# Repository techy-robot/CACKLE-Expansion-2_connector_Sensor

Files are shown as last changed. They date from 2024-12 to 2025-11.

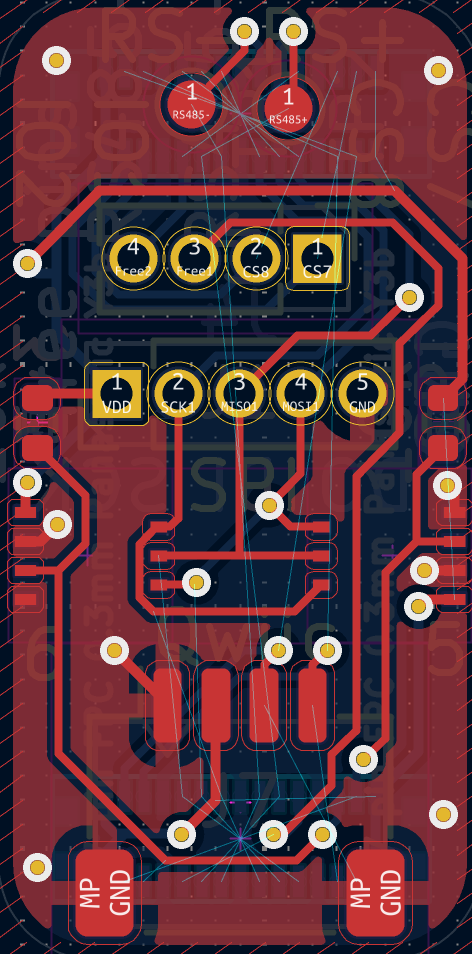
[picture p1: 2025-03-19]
media/2 conn Sensor Board Top.png

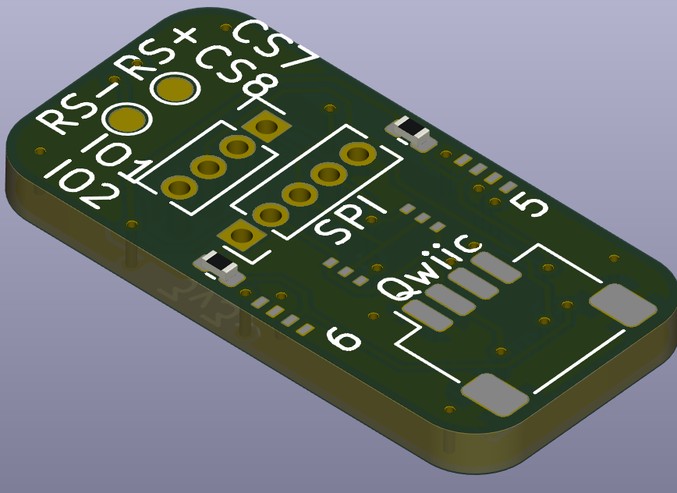
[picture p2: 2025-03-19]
media/2 conn Sensor Board 3D.png

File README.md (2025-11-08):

---
modified: 2025-11-07T22:07:14-07:00
---
# 2 connector Sensor Board

> [!TIP]
> This board is part of a larger modular control board ecosystem, [CACKLE](https://github.com/techy-robot/CACKLE)

This is a connector breakout board that spans between 2 vertical mezzanine connectors on a hub. It has one Qwiic connector, two nanoSPI connectors, and header breakouts for the free pins, chip select pins, and the SPI pins. It also has test pads for the RS485 bus. Essentially it breaks out every pin accessible via the mezzanine connectors.

One advantage this has over the single connector breakout is that this fits on normal sized hubs without needing a vertical spacer

Schematic PDF

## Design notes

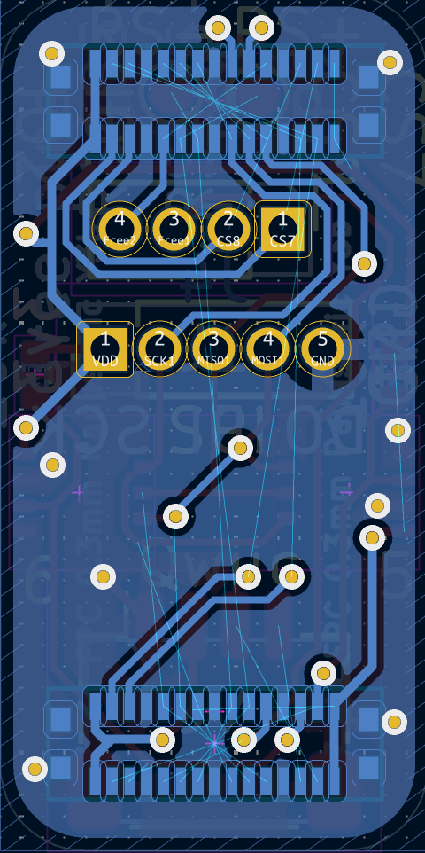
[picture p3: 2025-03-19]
media/2 conn Sensor Board Bottom.png

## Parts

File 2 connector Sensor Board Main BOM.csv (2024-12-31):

Id | Designator | Footprint | Quantity | Designation | Supplier and ref
1 | J1 | PinHeader_1x05_P1.27mm_Vertical | 1 | SPI
2 | J7 | JST_SH_SM04B-SRSS-TB_1x04-1MP_P1.00mm_Horizontal | 1 | JST SH
3 | R2,R4 | R_0402_1005Metric | 2 | 10k
4 | J3 | PinHeader_1x04_P1.27mm_Vertical | 1 | free pins
5 | J2,J5 | fpc_7pin_0.3mm_connector Panasonic | 2 | 7 pin FPC 0.3mm Panasonic Y3b
6 | J4,J15 | TE_mezzanine_conn_3-2363962-0 | 2 | TE 3-2363962-0 Connector

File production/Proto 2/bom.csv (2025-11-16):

Designator | Footprint | Quantity | Value | LCSC Part #
J1 | PinHeader_1x05_P1.27mm_Vertical | 1 | SPI
J15, J4 | TE_mezzanine_conn_3-2363962-0 | 2 | TE 3-2363962-0 Connector | C425104
J2, J5 | fpc_7pin_0.3mm_connector Panasonic | 2 | FPC 0.3mm Aces 51688-0070M
J3 | PinHeader_1x03_P1.27mm_Vertical | 1 | Prog Pins
J6 | PinHeader_1x02_P1.27mm_Vertical | 1 | Free Pins
J7 | JST_SH_SM04B-SRSS-TB_1x04-1MP_P1.00mm_Horizontal | 1 | JST SH | C160404
JP1, JP2 | SolderJumper-2_P1.3mm_Open_RoundedPad1.0x1.5mm | 2 | Jumper
R2, R4 | 0402 | 2 | 10k | C25744

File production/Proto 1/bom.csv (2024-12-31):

Designator | Footprint | Quantity | Value | LCSC Part #
J15, J4 | TE_mezzanine_conn_3-2363962-0 | 2 | TE 3-2363962-0 Connector | C425104
J7 | JST_SH_SM04B-SRSS-TB_1x04-1MP_P1.00mm_Horizontal | 1 | JST SH | C160404
R2, R4 | 0402 | 2 | 10k | C25744

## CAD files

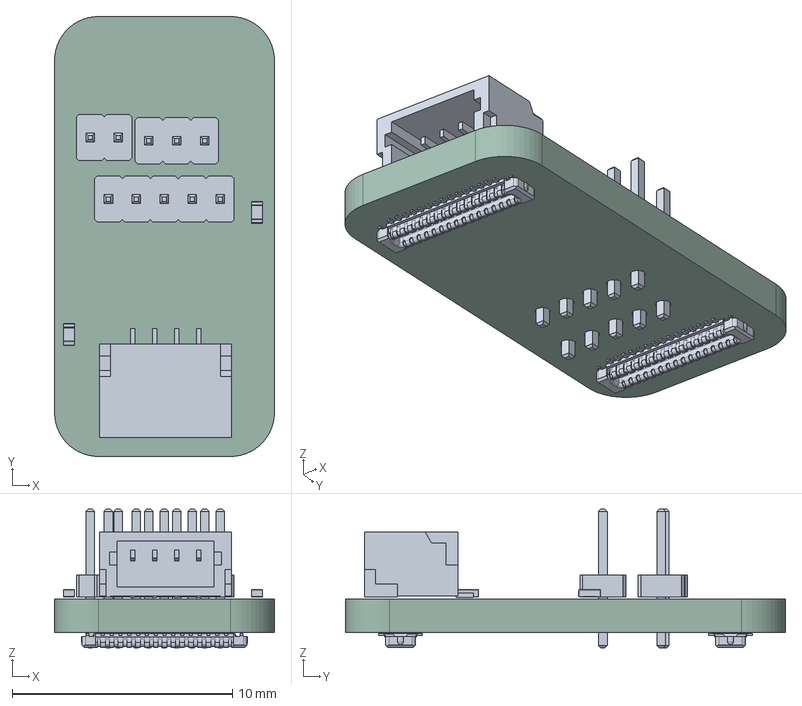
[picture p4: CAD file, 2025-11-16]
2 connector Sensor Board.step
10.0 x 20.0 x 6.30 mm
PinHeader_1x05_P1.27mm_Vertical
SM04B-SRSS-TB
R_0402_1005Metric x 2
PinHeader_1x03_P1.27mm_Vertical
PinHeader_1x02_P1.27mm_Vertical
TE c-3-2363962-0-a-3d x 2
2 connector Sensor Board_PCB

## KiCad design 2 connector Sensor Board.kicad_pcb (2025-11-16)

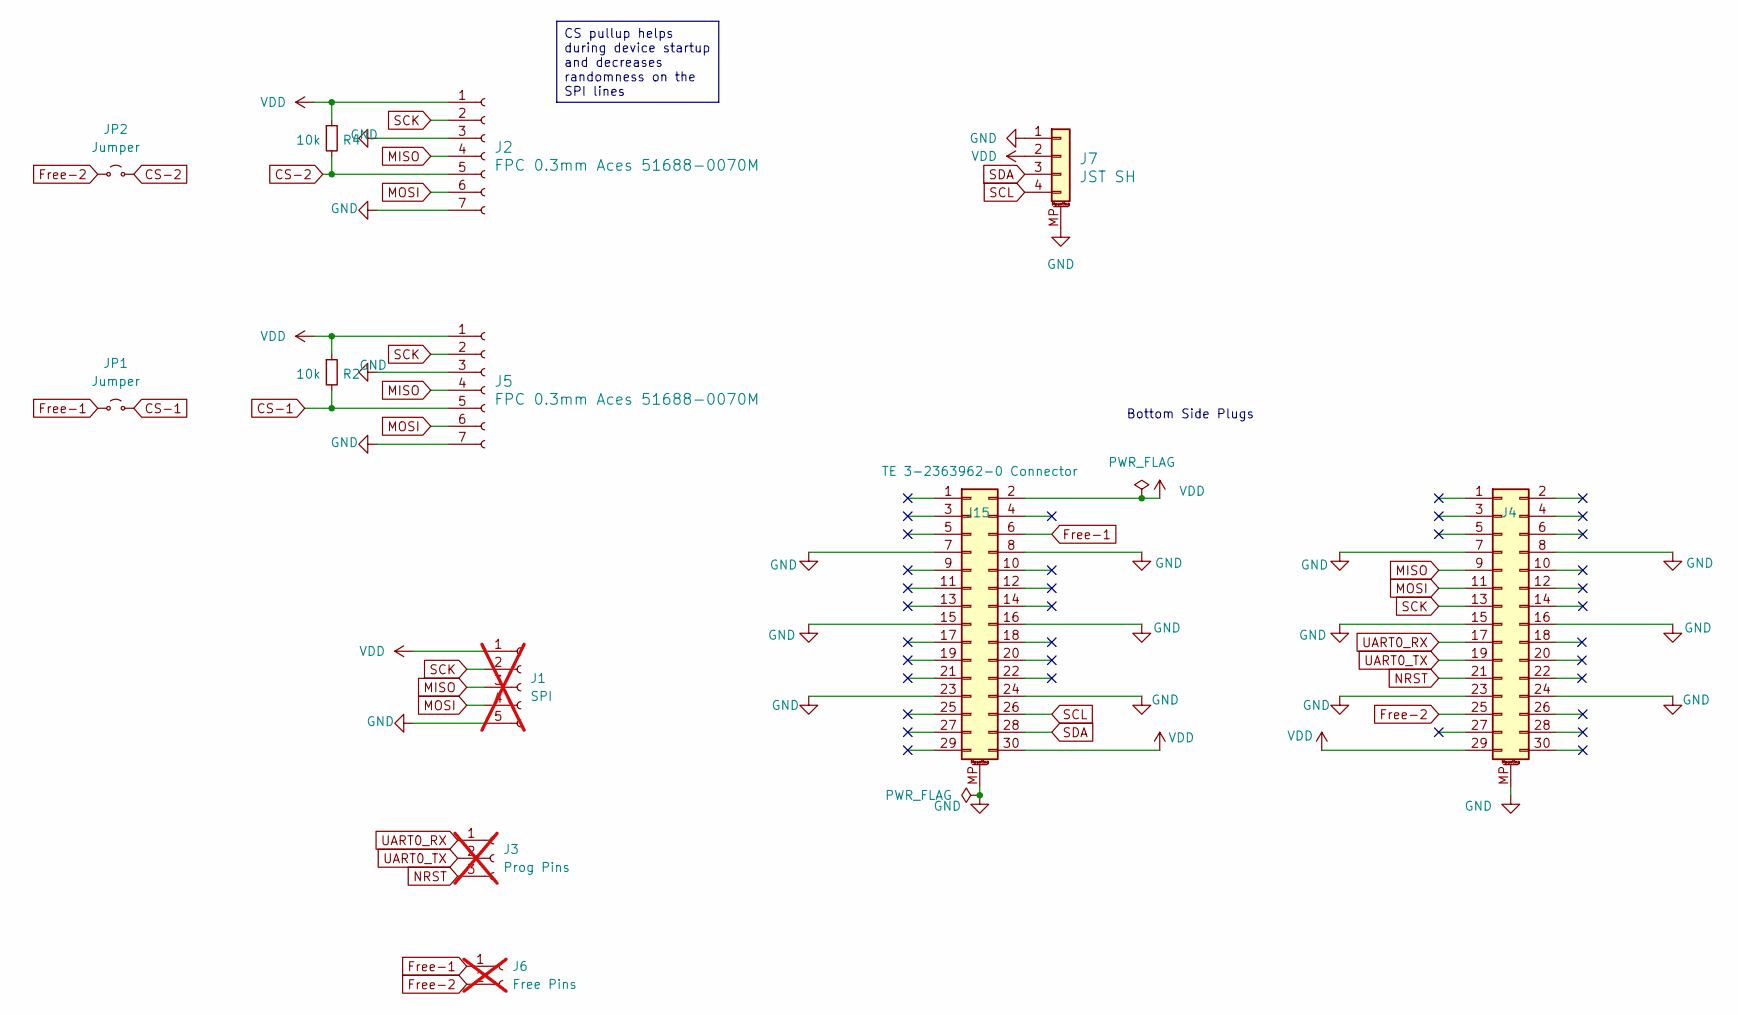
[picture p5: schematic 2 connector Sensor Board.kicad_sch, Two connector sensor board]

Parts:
J1: SPI; PinHeader_1x05_P1.27mm_Vertical; not fitted
J2, J5: FPC 0.3mm Aces 51688-0070M; fpc_7pin_0.3mm_connector Panasonic
J3: Prog Pins; PinHeader_1x03_P1.27mm_Vertical; not fitted
J4, J15: TE 3-2363962-0 Connector; TE_mezzanine_conn_3-2363962-0; LCSC C425104
J6: Free Pins; PinHeader_1x02_P1.27mm_Vertical; not fitted
J7: JST SH; JST_SH_SM04B-SRSS-TB_1x04-1MP_P1.00mm_Horizontal; LCSC C160404
JP1, JP2: Jumper; SolderJumper-2_P1.3mm_Open_RoundedPad1.0x1.5mm
R2, R4: 10k; R_0402_1005Metric; LCSC C25744

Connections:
CS-1: J5.5, JP1.2 (B), R2.2
CS-2: J2.5, JP2.2 (B), R4.2
Free-1: J6.1, J15.6, JP1.1 (A)
Free-2: J4.25, J6.2, JP2.1 (A)
GND: J1.5, J2.3, J2.7, J4.7, J4.8, J4.15, J4.16, J4.23, J4.24, J4.MP (MountPin), J5.3, J5.7, J7.1, J7.MP (MountPin), J15.7, J15.8, J15.15, J15.16, J15.23, J15.24, J15.MP (MountPin)
MISO: J1.3, J2.4, J4.9, J5.4
MOSI: J1.4, J2.6, J4.11, J5.6
NRST: J3.3, J4.21
SCK: J1.2, J2.2, J4.13, J5.2
SCL: J7.4, J15.26
SDA: J7.3, J15.28
UART0_RX: J3.1, J4.17
UART0_TX: J3.2, J4.19
VDD: J1.1, J2.1, J4.29, J5.1, J7.2, J15.2, J15.30, R2.1, R4.1

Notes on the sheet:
Bottom Side Plugs
CS pullup helps during device startup and decreases randomness on the SPI lines

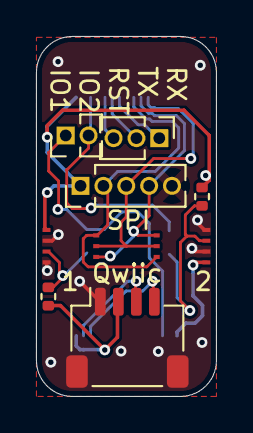
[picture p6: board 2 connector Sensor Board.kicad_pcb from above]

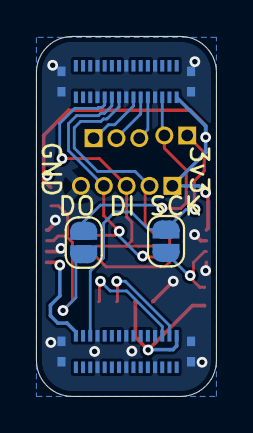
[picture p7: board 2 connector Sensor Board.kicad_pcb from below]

Board: 2 copper layers, 10.0 x 20.0 mm, 12 parts (4 on the bottom side), 14 nets.

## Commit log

2024-12-31 Rearranged design files
    Instead of "Kicad" the main design folder is now named "Hardware" since I have gerbers and notes besides the kicad files. I have also put my designs in their proper categories.
    [2 connector Sensor Board Main BOM.csv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]
2025-01-02 Added schematic PDFs for all boards
2025-01-04 Added gerber zip files
2025-01-13 Changed link names for schematic embeds not displayin
    In Obsidian I can see the pdf embeds perfectly fine, but Github doesn't want to show embedded PDFs. I changed the link alias to "Schematic PDF" so people know what the link is when it doesn't display
2025-10-10 Moved all current production files to Proto 1.
    I haven't made a 2nd prototype yet
    [2 connector Sensor Board-B_Cu.gbl, 2 connector Sensor Board-B_Mask.gbs, 2 connector Sensor Board-B_Paste.gbp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]
2025-11-16 Updated schematic with latest parts and pinout
    [2 connector Sensor Board.kicad_sch]
2025-11-16 Finished reroute
    [2 connector Sensor Board.kicad_pcb, 2 connector Sensor Board.kicad_sch]
2025-11-16 Finished redesign and export
    [2 connector Sensor Board.kicad_pcb, 2 connector Sensor Board.step, bom.csv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]

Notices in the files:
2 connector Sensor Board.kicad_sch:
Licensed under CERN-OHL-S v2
